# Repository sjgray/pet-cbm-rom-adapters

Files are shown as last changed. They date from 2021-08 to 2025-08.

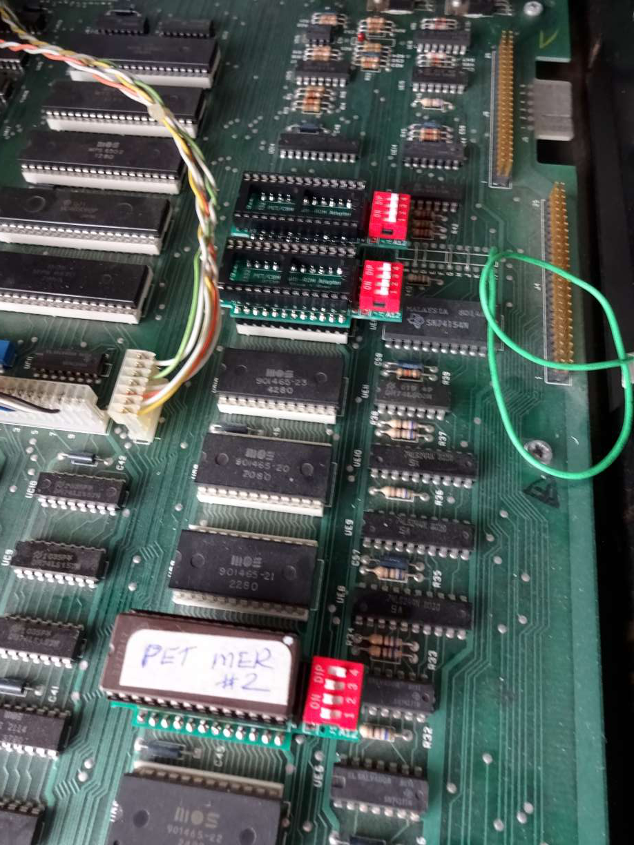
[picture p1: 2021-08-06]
pet-cbm-multirom/pics/DSC08003-P25.jpg

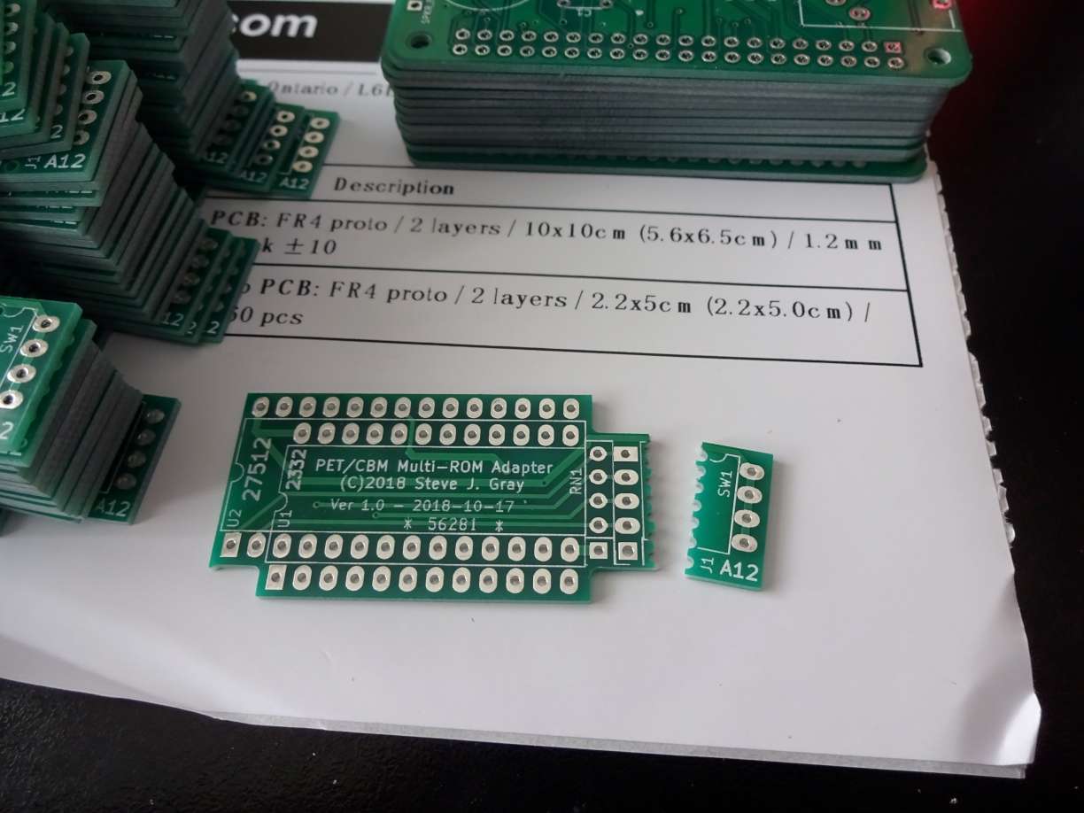
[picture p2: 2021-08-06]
pet-cbm-multirom/pics/DSC07974-P25.jpg

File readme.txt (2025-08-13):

PET/CBM Multi-ROM Adapters
==========================

These adapters allow you to combine multiple 4K ROMS
into one 64K ROM and select them via separate switches
or dip-switch.

The following are available:

1) PET-CBM-MULTIROM
2) MULTI-EDIT-ROM
3) 2332-MultiROM-PLCC

DECRIPTIONS
-----------

1) PET-CBM-MULTIROM

  - Up to 16 ROMs in one.
  - 4-position DIP SWITCH or off-board switches
  - DIP-SWITH section is removable
  - Suitable for adjacent ROM sockets on 4000/8000 boards
  - Suitable for 8296 KERNAL, EDIT, or BASIC sockets
  - Suitable for single 8296 OPTION rom socket
  - NOT suitable for both adjacent 8296 OPTION sockets
  - NOT suitable for SuperPET firmware ROMs

2) MULTI-EDIT-ROM

  - Up to 16 ROMs in one.
  - 4-position DIP SWITCH or off-board switches
  - Suitable for SuperPET EDIT, KERNAL and BASIC ROM sockets,
    but NOT adjacent sockets due to width of board

3) 2332-MultiROM-PLCC
  - Generally for PET ROM sockets
  - Replace any 2332 Masked ROM with a Winbond W27C010 or 0W27C020
  - Up to 16 4K banks
  - Board is same width as socket and only slightly longer

More information is available on the web:

http://www.cbmsteve.ca
http://www.cbmsteve.ca/multirom/index.html

Steve

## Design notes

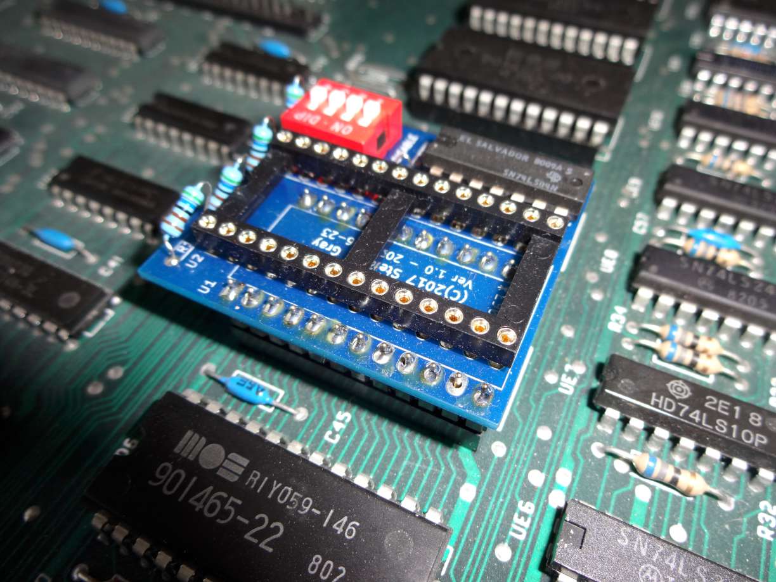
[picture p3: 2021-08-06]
multi-edit-rom/Pics/DSC06890-P25.jpg

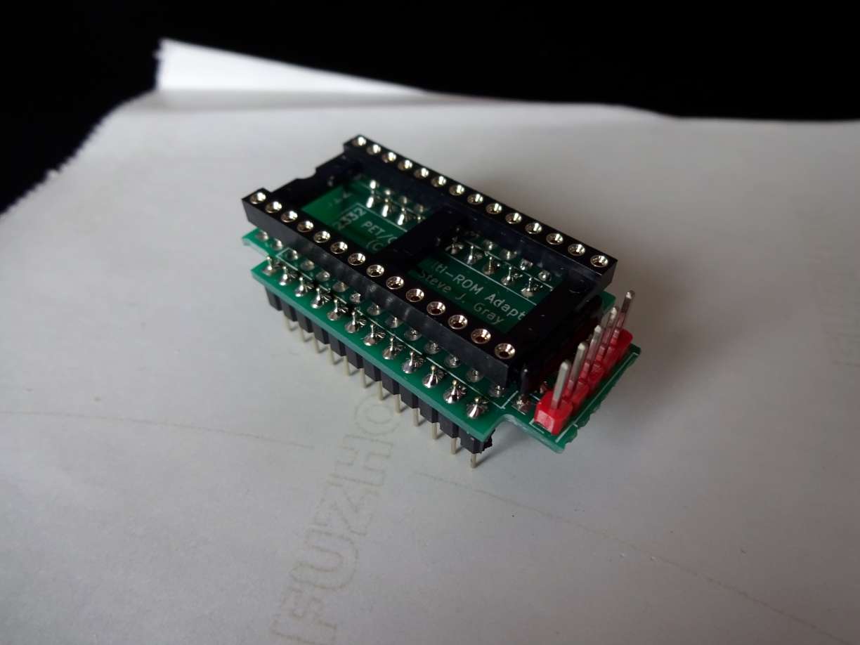
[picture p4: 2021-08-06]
pet-cbm-multirom/pics/DSC08017-P25.jpg

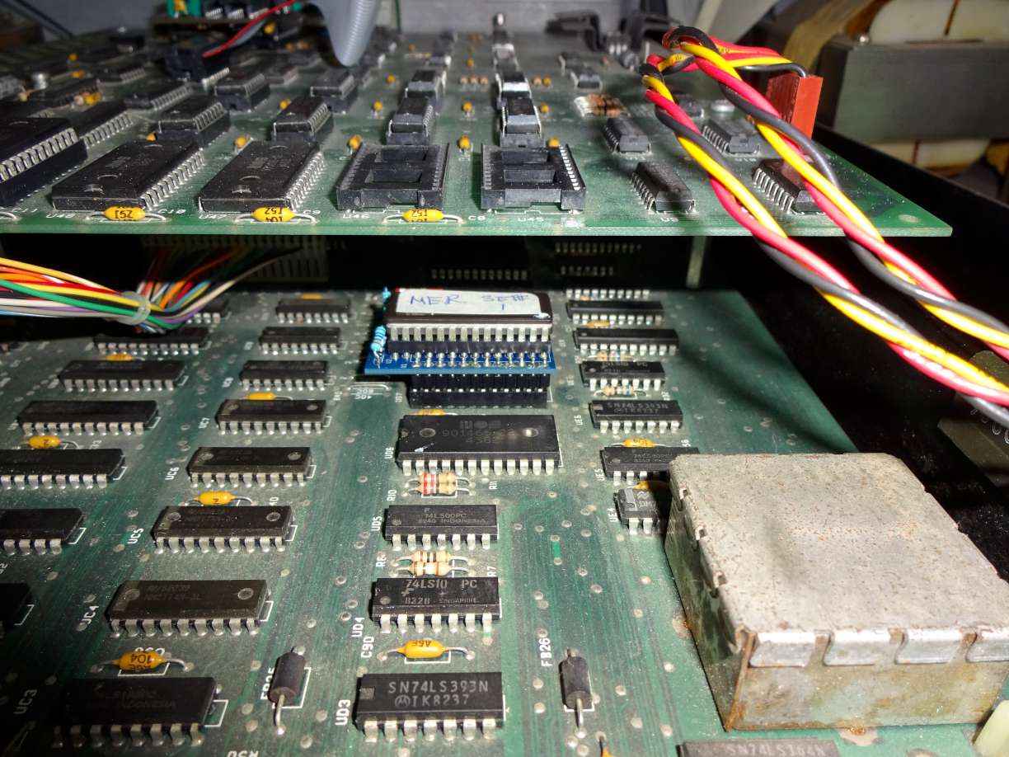
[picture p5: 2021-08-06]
multi-edit-rom/Pics/superpet-P25.jpg

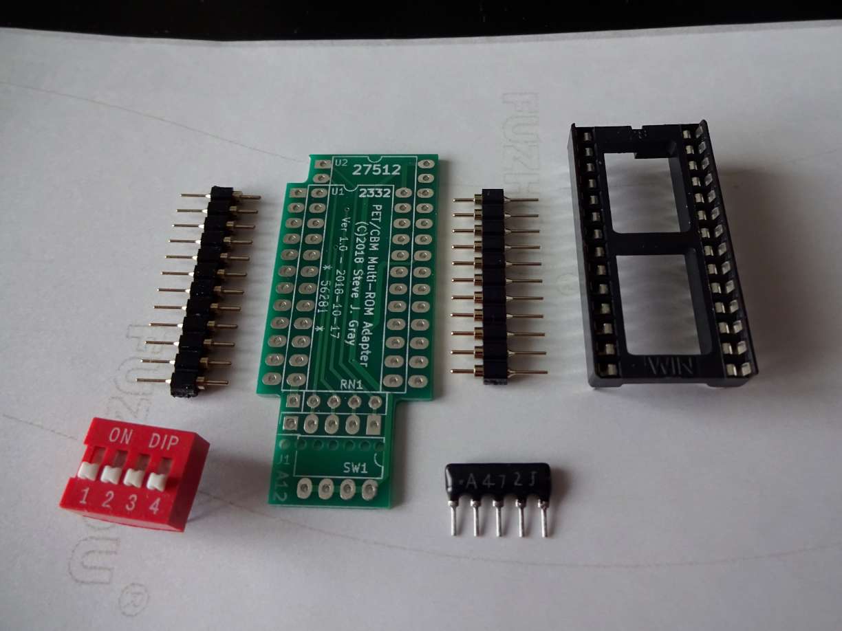
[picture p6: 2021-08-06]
pet-cbm-multirom/pics/DSC07982-P25.jpg

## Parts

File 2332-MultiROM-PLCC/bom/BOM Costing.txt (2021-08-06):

ebay#		qty	desc						 USD$ 	unit$
291623726753	10	28Pin wide DIP Round IC Sockets			 3.48	.34
262715573930	50	A05 10K ohm 5-pin resistor network		 2.98	.06
253823347087	10	Header Strip Connector 40Pin 2.54mm Round Male   3.62	.36
252024566074	10	4-position DIP Switch block			  .99	.10
181595821013	10	27C512 EPROM					 8.88	.89
Steve's PCB	10	PET/CBM Multi-ROM ($20.00+shipping)		 5.20	.52

Total: USD$2.27

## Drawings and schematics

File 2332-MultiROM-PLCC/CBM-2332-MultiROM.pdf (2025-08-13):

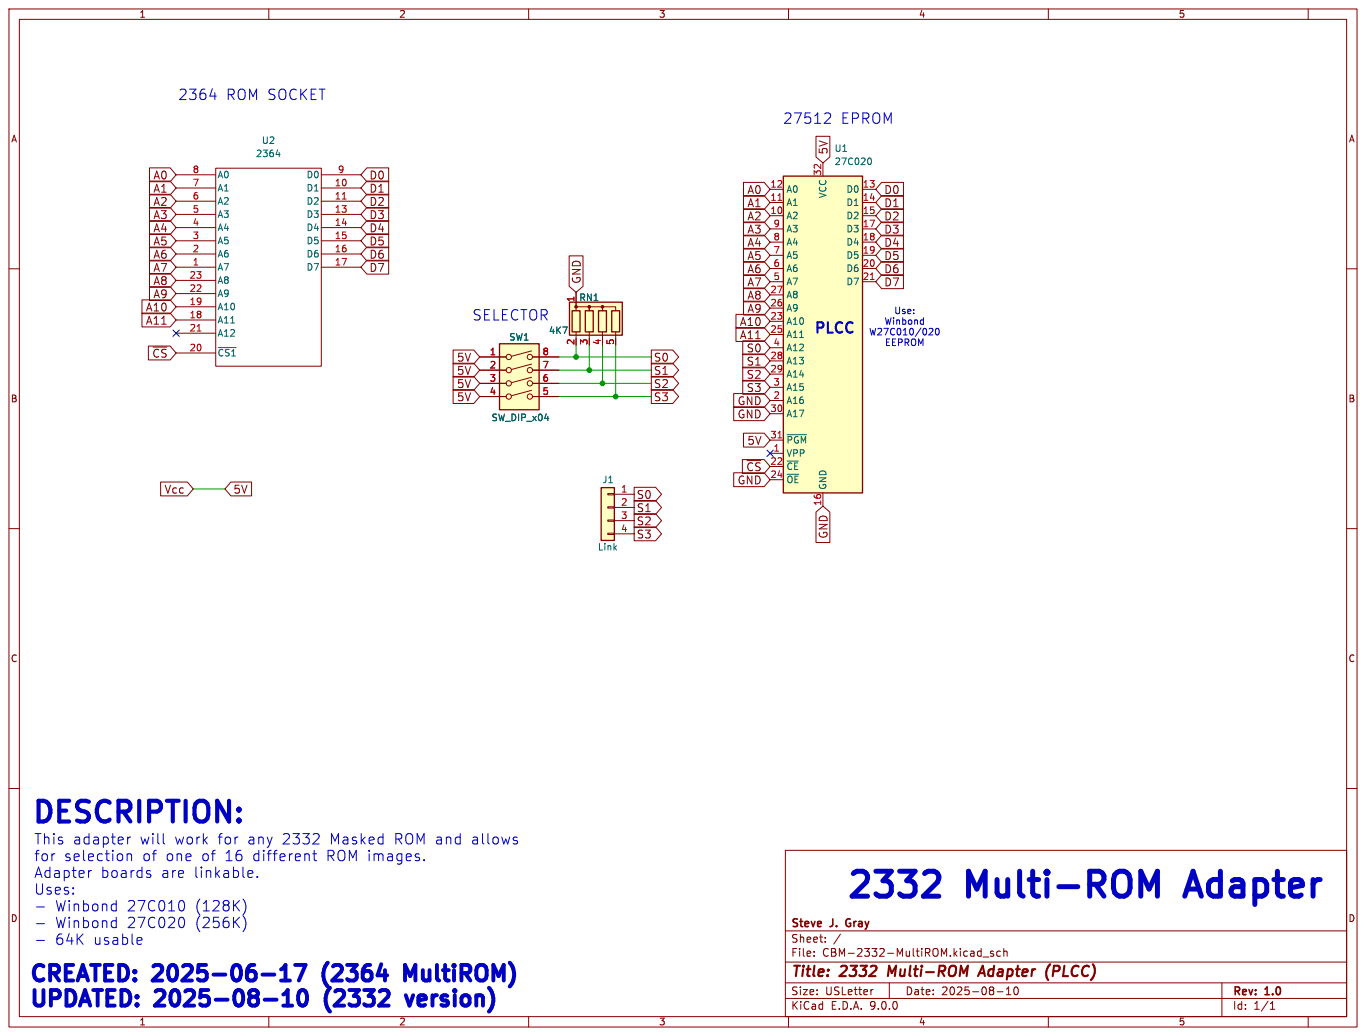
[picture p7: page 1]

Use: Winbond W27C010/020 EEPROM DESCRIPTION:

This adapter will work for any 2332 Masked ROM and allows
Adapter boards are linkable.
Uses: - Winbond 27C010 (128K)

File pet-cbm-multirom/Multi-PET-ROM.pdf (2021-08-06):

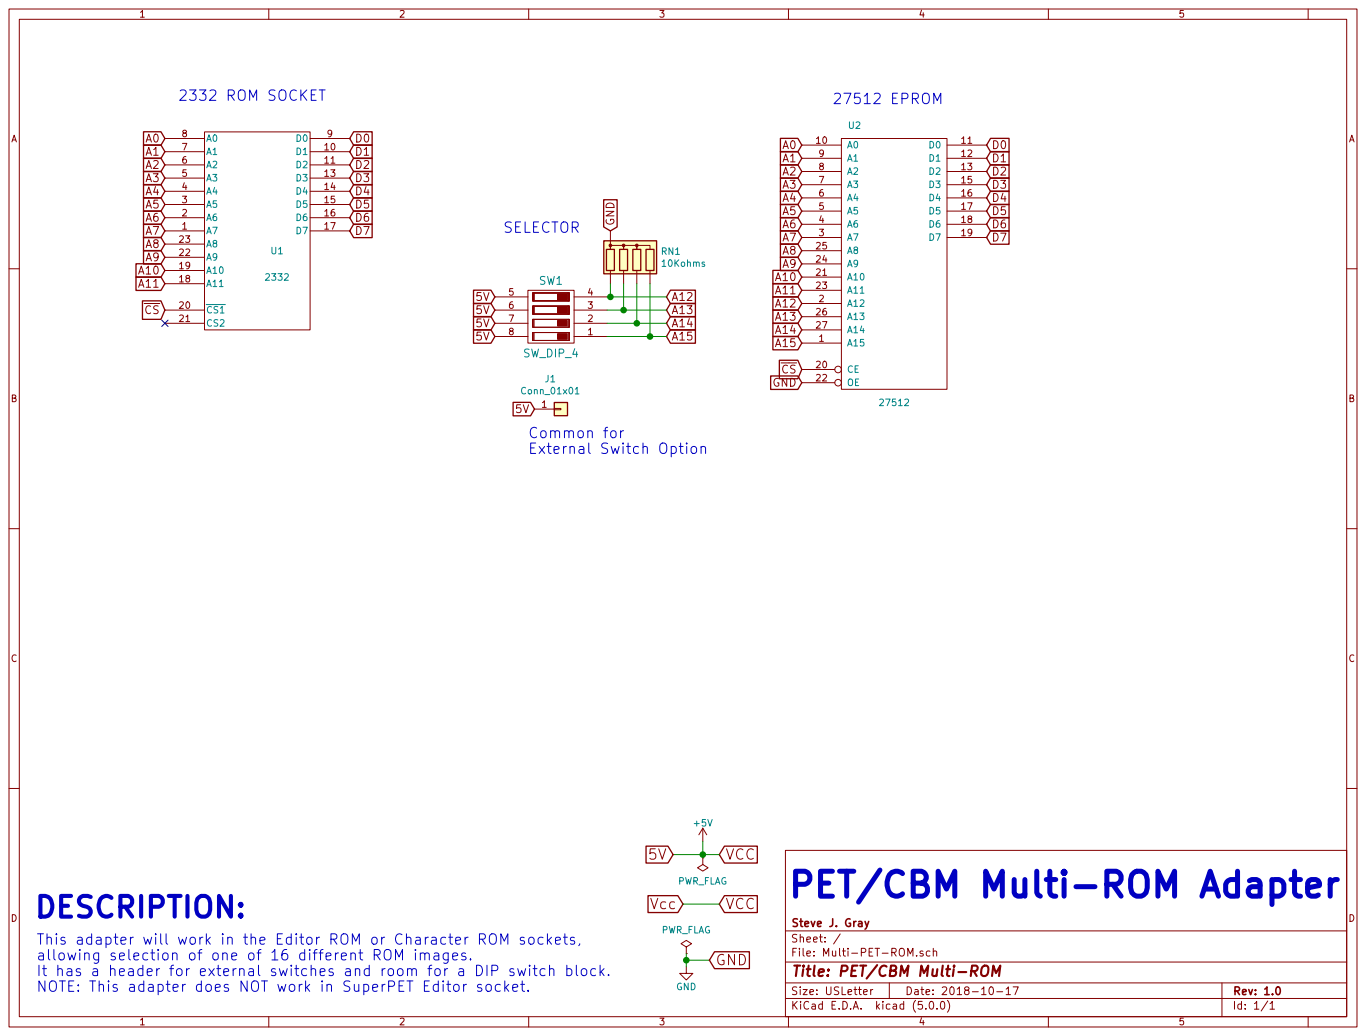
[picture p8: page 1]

PET/CBM Multi-ROM Adapter

This adapter will work in the Editor ROM or Character ROM sockets,
allowing selection of one of 16 different ROM images.
It has a header for external switches and room for a DIP switch block.
NOTE: This adapter does NOT work in SuperPET Editor socket.

File: Multi-PET-ROM.sch Sheet: / Steve J. Gray

Id: 1/1 Title: PET/CBM Multi-ROM

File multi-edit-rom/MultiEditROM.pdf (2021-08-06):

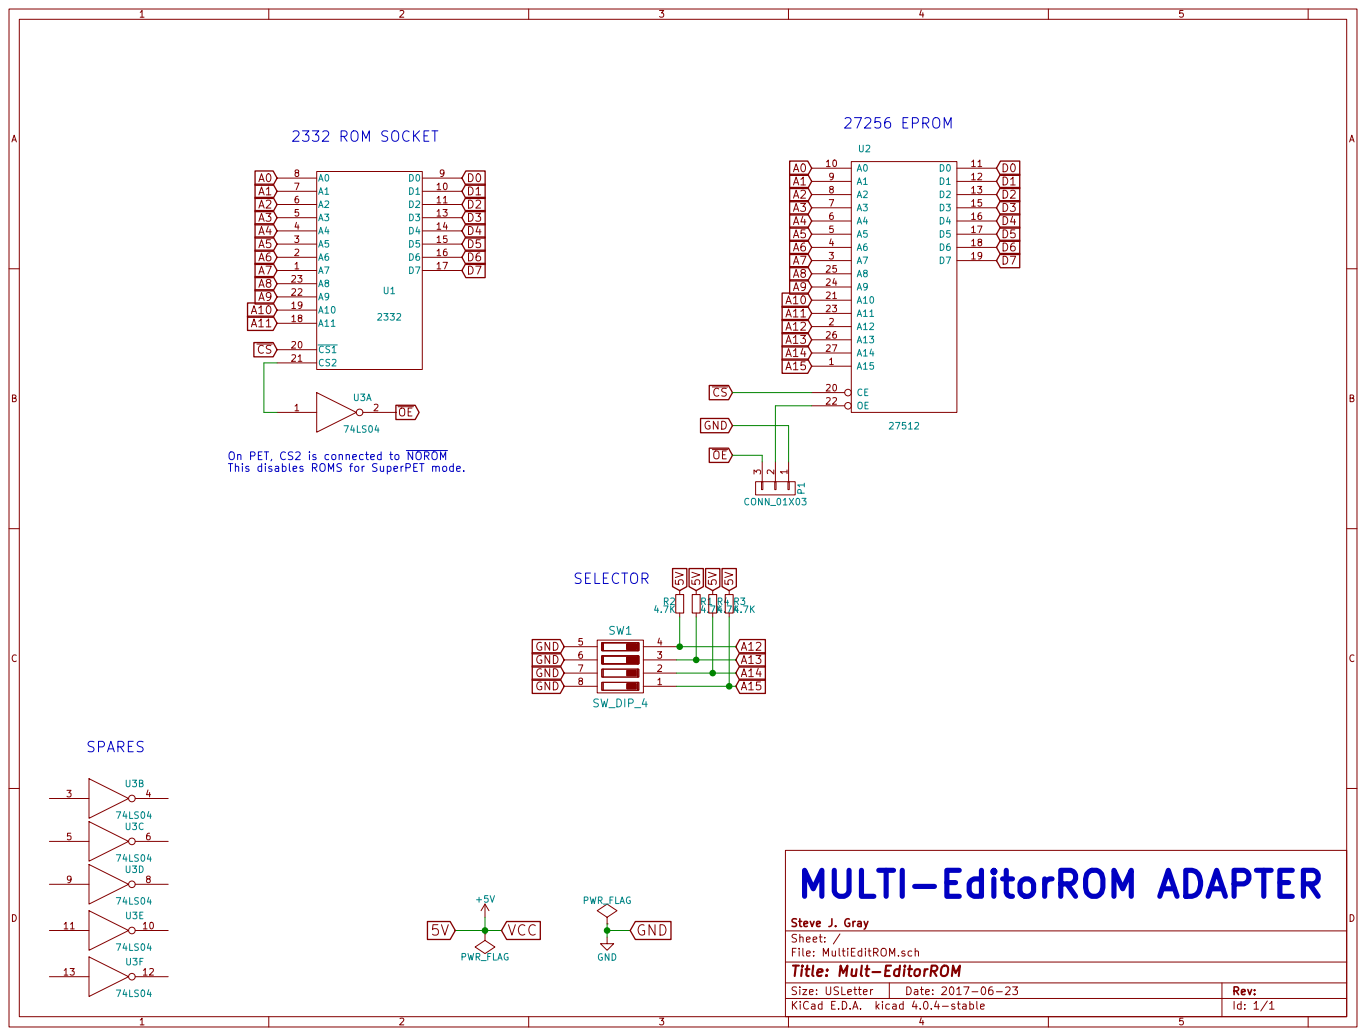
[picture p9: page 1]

On PET, CS2 is connected to NOROM
This disables ROMS for SuperPET mode.

File: MultiEditROM.sch Sheet: / Steve J. Gray

Id: 1/1 Title: Mult-EditorROM

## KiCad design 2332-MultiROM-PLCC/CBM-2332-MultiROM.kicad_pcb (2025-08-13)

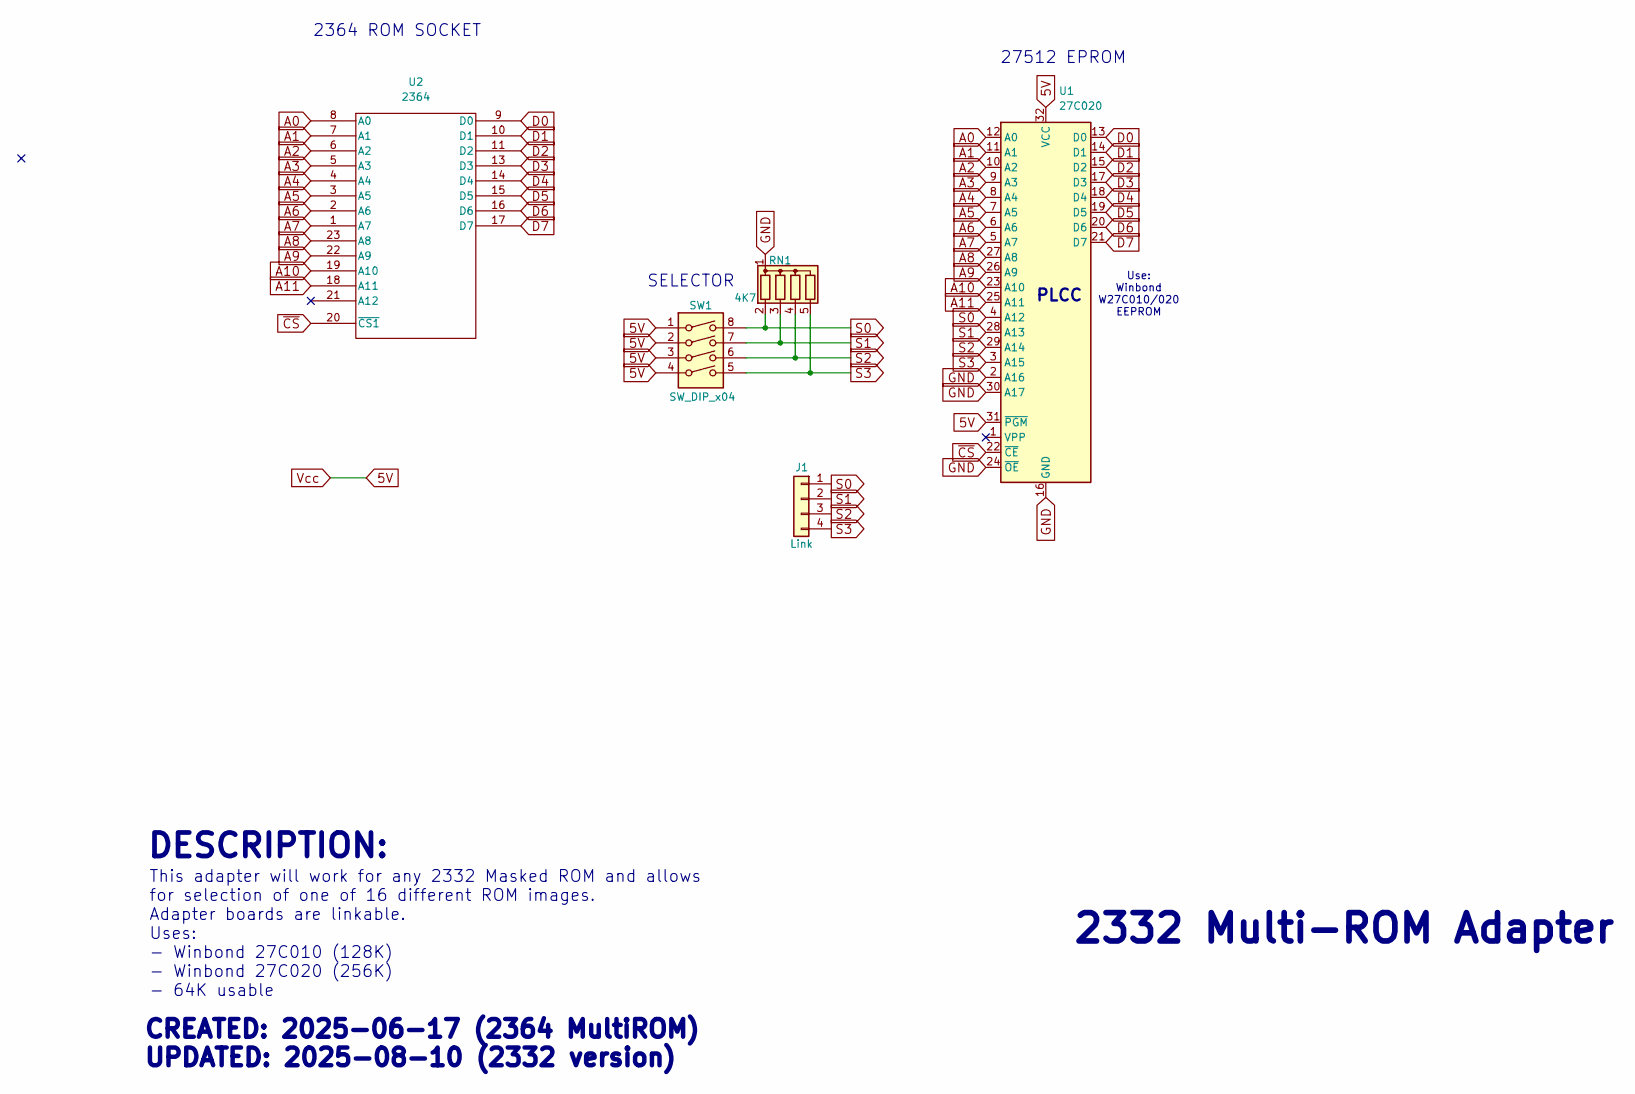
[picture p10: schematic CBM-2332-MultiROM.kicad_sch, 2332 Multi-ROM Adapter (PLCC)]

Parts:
J1: Link; PinHeader_1x04_P2.54mm_Vertical
RN1: 4K7; R_Array_SIP5
SW1: SW_DIP_x04; SW_DIP_SPSTx04_Slide_6.7x11.72mm_W7.62mm_P2.54mm_LowProfile
U1: 27C020; PLCC-32_THT-Socket
U2: 2364; DIP-24_W15.24mm_Socket

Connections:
5V: SW1.1, SW1.2, SW1.3, SW1.4, U1.31 (~PGM), U1.32 (VCC), U2.24 (Vcc)
A0: U1.12 (A0), U2.8 (A0)
A1: U1.11 (A1), U2.7 (A1)
A2: U1.10 (A2), U2.6 (A2)
A3: U1.9 (A3), U2.5 (A3)
A4: U1.8 (A4), U2.4 (A4)
A5: U1.7 (A5), U2.3 (A5)
A6: U1.6 (A6), U2.2 (A6)
A7: U1.5 (A7), U2.1 (A7)
A8: U1.27 (A8), U2.23 (A8)
A9: U1.26 (A9), U2.22 (A9)
A10: U1.23 (A10), U2.19 (A10)
A11: U1.25 (A11), U2.18 (A11)
D0: U1.13 (D0), U2.9 (D0)
D1: U1.14 (D1), U2.10 (D1)
D2: U1.15 (D2), U2.11 (D2)
D3: U1.17 (D3), U2.13 (D3)
D4: U1.18 (D4), U2.14 (D4)
D5: U1.19 (D5), U2.15 (D5)
D6: U1.20 (D6), U2.16 (D6)
D7: U1.21 (D7), U2.17 (D7)
GND: RN1.1 (common), U1.2 (A16), U1.16 (GND), U1.24 (~OE), U1.30 (A17), U2.12 (GND)
S0: J1.1, RN1.2 (R1), SW1.8, U1.4 (A12)
S1: J1.2, RN1.3 (R2), SW1.7, U1.28 (A13)
S2: J1.3, RN1.4 (R3), SW1.6, U1.29 (A14)
S3: J1.4, RN1.5 (R4), SW1.5, U1.3 (A15)
~CS: U1.22 (~CE), U2.20 (~CS1)

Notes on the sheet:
CREATED: 2025-06-17 (2364 MultiROM) UPDATED: 2025-08-10 (2332 version)
This adapter will work for any 2332 Masked ROM and allows for selection of one of 16 different ROM images. Adapter boards are linkable. Uses: - Winbond 27C010 (128K) - Winbond 27C020 (256K) - 64K usable
2364 ROM SOCKET
PLCC
Use: Winbond W27C010/020 EEPROM
27512 EPROM
SELECTOR
DESCRIPTION:
2332 Multi-ROM Adapter

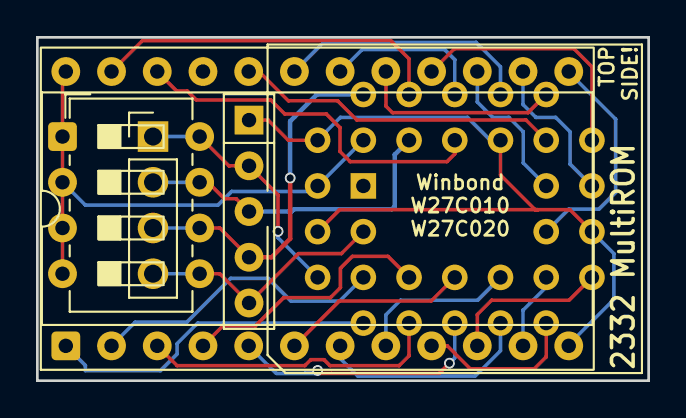
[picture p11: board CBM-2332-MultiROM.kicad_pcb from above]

Board: 2 copper layers, 34.0 x 19.1 mm, 5 parts (0 on the bottom side), 27 nets.

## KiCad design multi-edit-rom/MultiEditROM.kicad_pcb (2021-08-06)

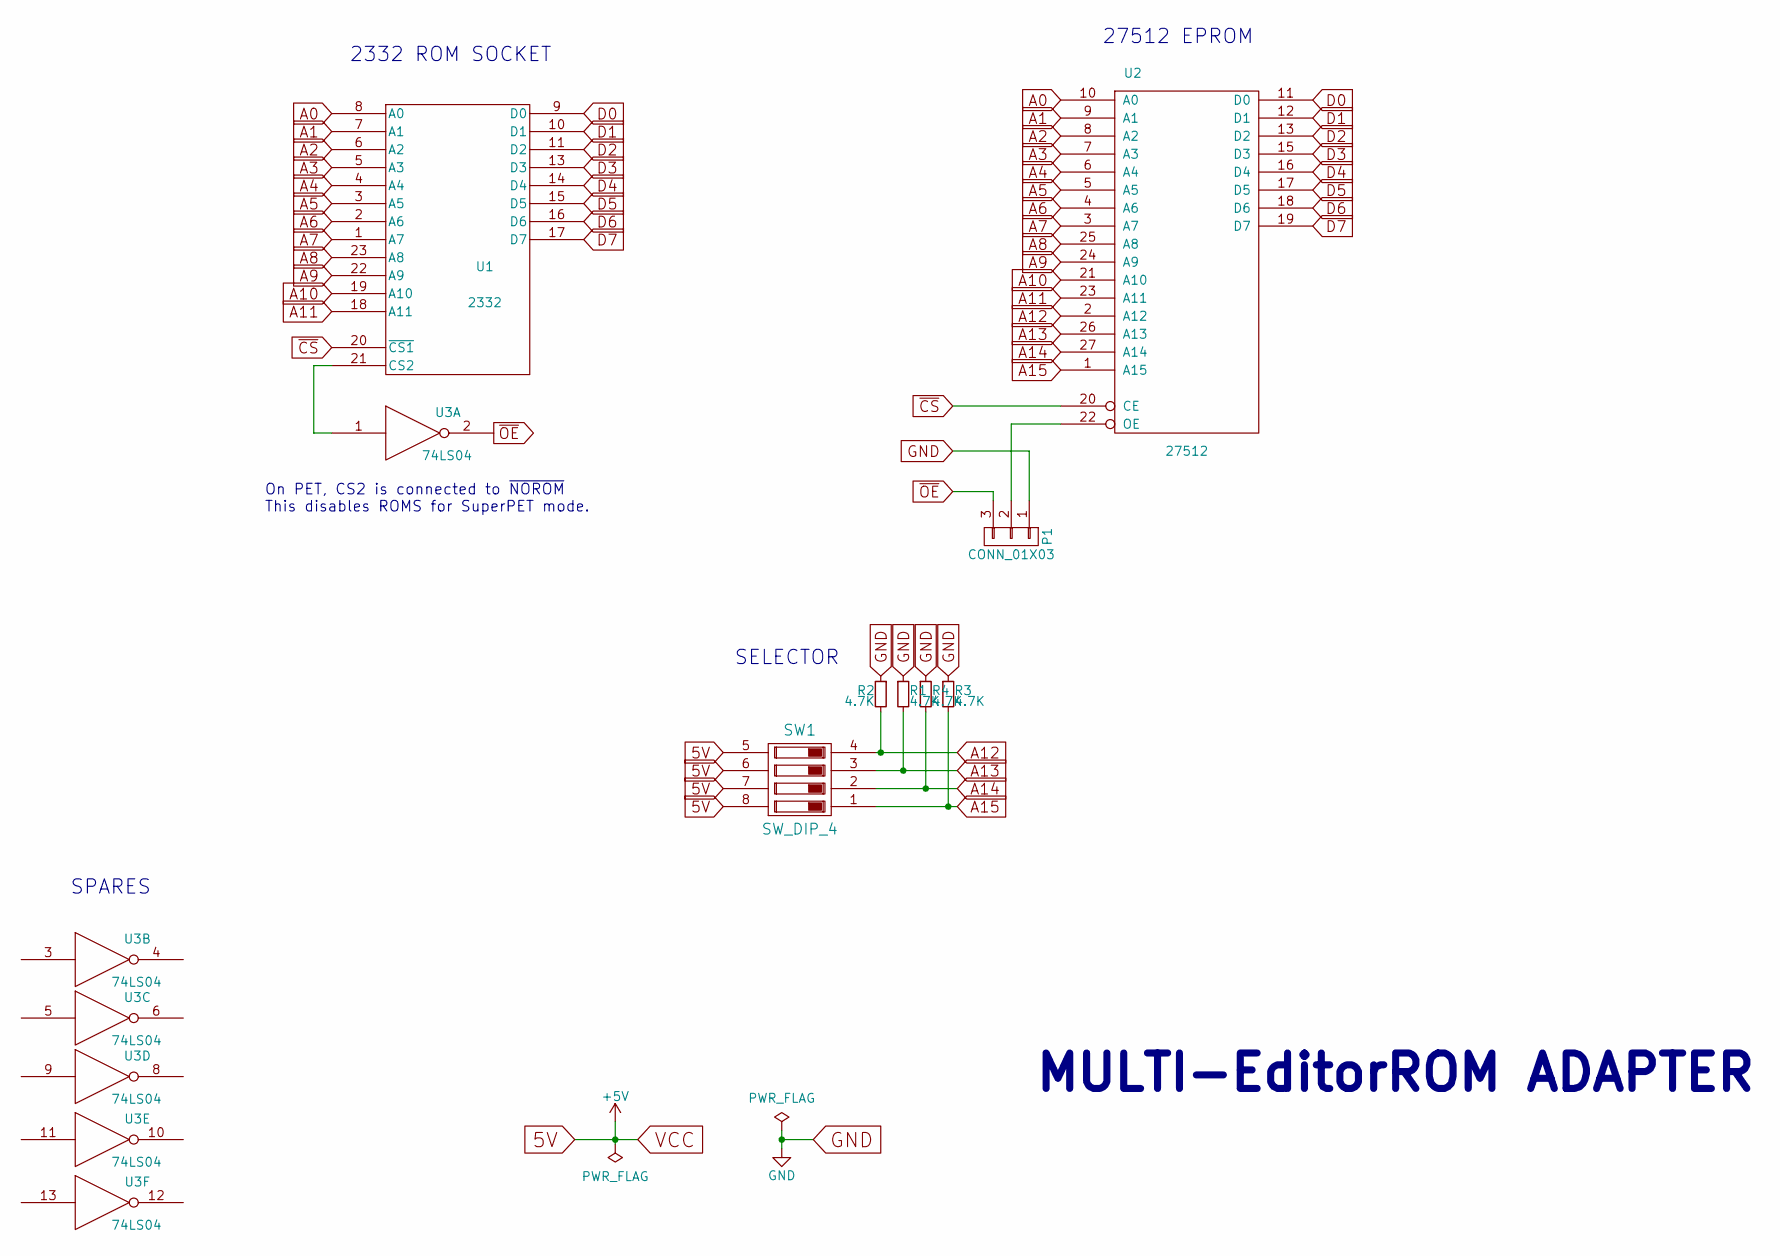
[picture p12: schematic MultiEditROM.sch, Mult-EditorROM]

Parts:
P1: CONN_01X03; Pin_Header_Straight_1x03_Pitch1.27mm
R1, R2, R3, R4: 4.7K; R_Axial_DIN0204_L3.6mm_D1.6mm_P5.08mm_Horizontal
SW1: SW_DIP_4; DIP-8_W7.62mm_LongPads
U1: 2332; DIP-24_W15.24mm_LongPads
U2: 27512; DIP-28_W15.24mm_LongPads
U3: 74LS04; DIP-14_W7.62mm_LongPads

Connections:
5V: SW1.5, SW1.6, SW1.7, SW1.8, U1.24 (Vcc), U2.28 (VCC), U3.14 (VCC)
A0: U1.8 (A0), U2.10 (A0)
A1: U1.7 (A1), U2.9 (A1)
A2: U1.6 (A2), U2.8 (A2)
A3: U1.5 (A3), U2.7 (A3)
A4: U1.4 (A4), U2.6 (A4)
A5: U1.3 (A5), U2.5 (A5)
A6: U1.2 (A6), U2.4 (A6)
A7: U1.1 (A7), U2.3 (A7)
A8: U1.23 (A8), U2.25 (A8)
A9: U1.22 (A9), U2.24 (A9)
A10: U1.19 (A10), U2.21 (A10)
A11: U1.18 (A11), U2.23 (A11)
A12: R2.2, SW1.4, U2.2 (A12)
A13: R1.2, SW1.3, U2.26 (A13)
A14: R4.2, SW1.2, U2.27 (A14)
A15: R3.2, SW1.1, U2.1 (A15)
D0: U1.9 (D0), U2.11 (D0)
D1: U1.10 (D1), U2.12 (D1)
D2: U1.11 (D2), U2.13 (D2)
D3: U1.13 (D3), U2.15 (D3)
D4: U1.14 (D4), U2.16 (D4)
D5: U1.15 (D5), U2.17 (D5)
D6: U1.16 (D6), U2.18 (D6)
D7: U1.17 (D7), U2.19 (D7)
GND: P1.1, R1.1, R2.1, R3.1, R4.1, U1.12 (GND), U2.14 (GND), U3.7 (GND)
unnamed: P1.2, U2.22 (OE)
unnamed: U1.21 (CS2), U3.1
~CS: U1.20 (~CS1), U2.20 (CE)
~OE: P1.3, U3.2

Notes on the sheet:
2332 ROM SOCKET
27512 EPROM
SELECTOR
MULTI-EditorROM ADAPTER
On PET, CS2 is connected to ~NOROM~ This disables ROMS for SuperPET mode.
SPARES

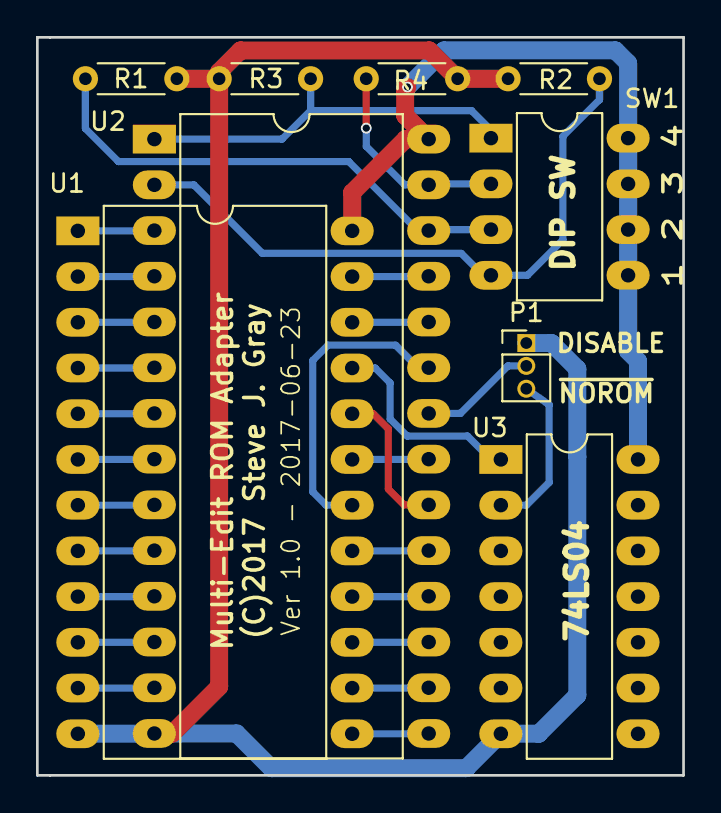
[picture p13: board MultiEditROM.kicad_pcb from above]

Board: 2 copper layers, 35.9 x 41.0 mm, 9 parts (0 on the bottom side), 30 nets.

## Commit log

2021-08-06 Initial commit
    Includes PET/CBM MultiROM and Multi-EditROM adapters
    [Multi-PET-ROM.kicad_pcb, Multi-PET-ROM.sch, MultiEditROM.kicad_pcb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]
2025-08-13 Add 2332 MultiROM PLCC
    This has the same functionality as the other switcher but uses a Winbond PLCC EEPROM which are available, inexpensive, and smaller in size than the DIP version. The pcb is the same width as the DIP socket and only slightly longer meaning it will interfere less with other surrounding parts, and will also work in the 8296 motherboards so you can install two side-by-side in the OptionROM sockets, plus they will not interfere with the expansion headers.
    [CBM-2332-MultiROM-B_Cu.gbr, CBM-2332-MultiROM-B_Mask.gbr, CBM-2332-MultiROM-B_Silkscreen.gbr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]

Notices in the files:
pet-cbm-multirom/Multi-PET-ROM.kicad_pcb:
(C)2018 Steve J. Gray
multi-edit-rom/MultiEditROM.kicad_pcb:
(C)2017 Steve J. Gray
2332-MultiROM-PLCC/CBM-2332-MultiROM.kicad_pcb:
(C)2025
